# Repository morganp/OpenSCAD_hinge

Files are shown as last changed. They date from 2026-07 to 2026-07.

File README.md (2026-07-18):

# OpenSCAD_hinge

Parametric hinge library, plain OpenSCAD (no `BOSL2`, no third-party `include`s), for boxes,
lids, and wooden doors/cabinets. Loadable standalone in real OpenSCAD and by
[OpenSCAD-gui](../OpenSCAD-gui) (a custom JS OpenSCAD engine that resolves `include`/`use`
against its own drag-drop file provider and does not bundle BOSL2).

All modules live in `hinge_library.scad`. Each hinge type has a demo file under `examples/`
and a rendered preview under `renders/`.

## Usage

```openscad
include <hinge_library.scad>

knuckle_hinge(leaf_length=40, leaf_width=15, leaf_thickness=3, knuckle_od=6, knuckle_count=5);
```

Hinge axis convention: the barrel/knuckle axis runs along **Y** at x=0, z=knuckle radius, so
the closed hinge sits flat on the **Z=0** plane (printable as-is, barrel resting on the bed).
Leaf 1 occupies X<0, leaf 2 occupies X≥0, and the two leaves are separate solids with print
clearances, so each can be positioned/unioned directly onto its mating part. Units are mm.

---

## knuckle_hinge — print-in-place box lid hinge

Interleaved barrel knuckles across two leaves. By default the pin is integral to leaf 1 (its
knuckles are solid with the pin) and leaf 2's knuckles are bored with radial clearance, so the
part prints in place and articulates with no assembly. Set `integral_pin=false` for a
bored-both-sides hinge with an optional separately printed pin.

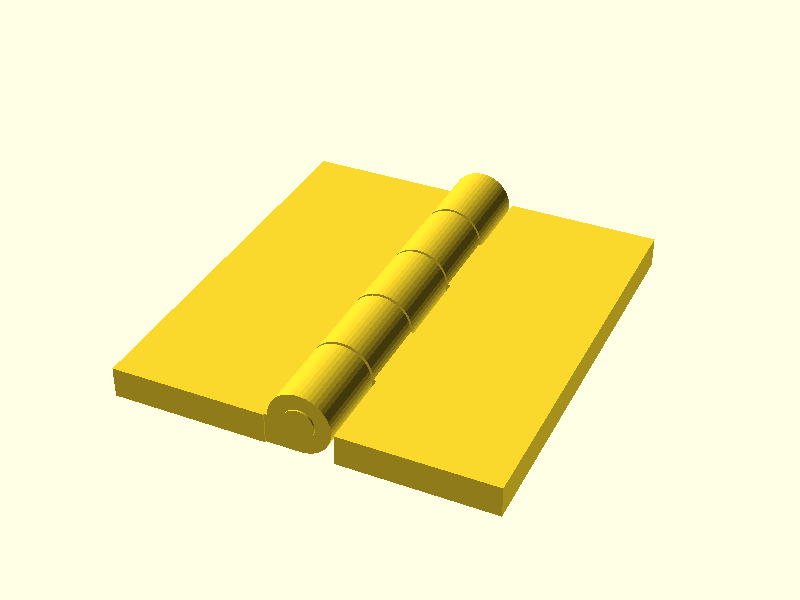
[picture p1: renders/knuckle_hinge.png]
knuckle_hinge render

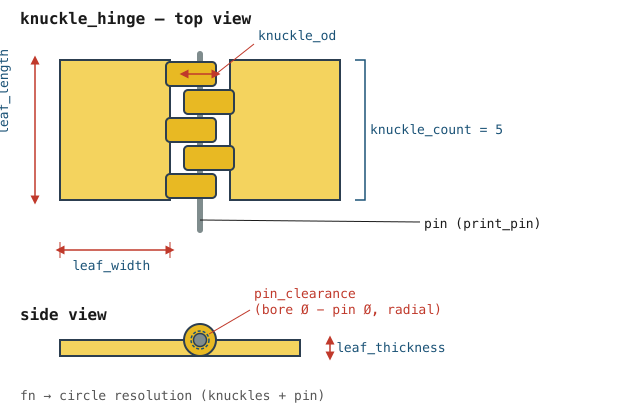
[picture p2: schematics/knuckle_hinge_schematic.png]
knuckle_hinge schematic


**[▶ Open in SCAD Studio](https://lizard-spock.co.uk/openscad-gui/?github=morganp/OpenSCAD_hinge/examples/knuckle_hinge_demo.scad)** — view this demo in the browser, no install.

| Parameter | Default | Meaning |
|---|---|---|
| `leaf_length` | 40 | Hinge length along the axis (Y) |
| `leaf_width` | 15 | Depth of each leaf plate (X), per leaf |
| `leaf_thickness` | 3 | Leaf plate thickness (Z) |
| `knuckle_od` | 6 | Knuckle/barrel outer diameter |
| `knuckle_count` | 5 | Number of knuckles across both leaves (odd = pin captive at both ends) |
| `pin_d` | 0 | Pin diameter; 0 = auto (`knuckle_od / 2`) |
| `pin_clearance` | 0.25 | Radial clearance between pin and knuckle bore |
| `knuckle_gap` | 0.3 | Axial clearance between adjacent knuckles, and leaf-to-barrel gap |
| `integral_pin` | true | Pin fused to leaf 1's knuckles (print-in-place, no assembly); `parts="both"` only, lone leaves are always bored |
| `print_pin` | false | With `integral_pin=false`: emit a loose pin beside the hinge |
| `cap_thickness` | 1.5 | `parts="caps"`: end cap flange thickness |
| `cap_plug_depth` | 0 | `parts="caps"`: cap stub depth into the bore; 0 = auto (half an end knuckle) |
| `parts` | "both" | `"both"` / `"leaf1"` / `"leaf2"` / `"pin"` / `"caps"`: emit one component only; a lone leaf is always bored for a loose pin, printed separately via `"pin"`, and `"caps"` emits a pair of gluable end caps that retain a cut-to-length metal rod pin |
| `fn` | 48 | `$fn`-style circle resolution for knuckles and pin |

---

## piano_hinge — continuous knuckle hinge, cut to any length

Same knuckle geometry as `knuckle_hinge`, but knuckle count is derived from `length` and a
target `knuckle_pitch`, for long lids needing even load distribution.

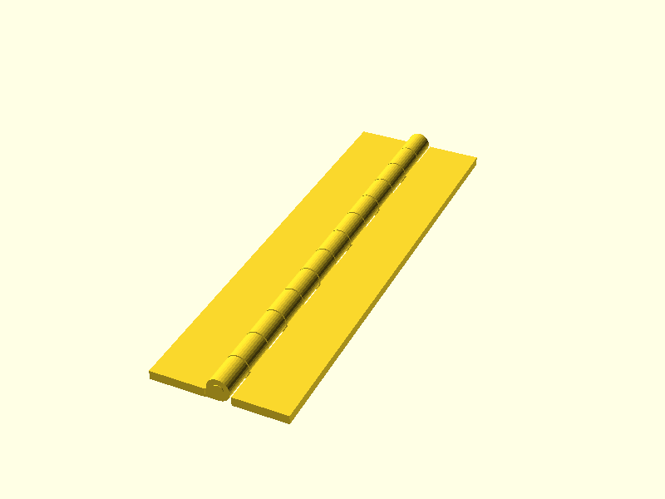
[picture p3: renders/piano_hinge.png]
piano_hinge render

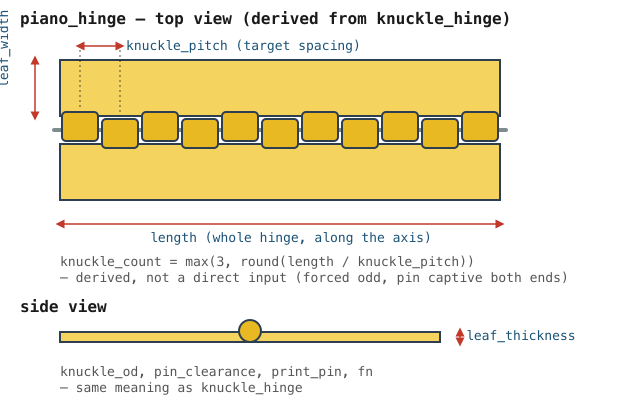
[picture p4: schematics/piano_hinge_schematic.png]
piano_hinge schematic


**[▶ Open in SCAD Studio](https://lizard-spock.co.uk/openscad-gui/?github=morganp/OpenSCAD_hinge/examples/piano_hinge_demo.scad)** — view this demo in the browser, no install.

| Parameter | Default | Meaning |
|---|---|---|
| `length` | 100 | Total hinge length along the axis |
| `leaf_width` | 12 | Depth of each leaf plate |
| `leaf_thickness` | 2 | Leaf plate thickness |
| `knuckle_od` | 5 | Knuckle outer diameter |
| `knuckle_pitch` | 8 | Target spacing between knuckle centers — knuckle count derived from `length / knuckle_pitch`, rounded up to odd, not set directly |
| `pin_d` | 0 | Pin diameter; 0 = auto |
| `pin_clearance` | 0.25 | Radial clearance between pin and bore |
| `knuckle_gap` | 0.3 | Axial knuckle clearance and leaf-to-barrel gap |
| `integral_pin` | true | Print-in-place pin fused to leaf 1; `parts="both"` only, lone leaves are always bored |
| `print_pin` | false | With `integral_pin=false`: emit a loose pin beside the hinge |
| `cap_thickness` | 1.5 | `parts="caps"`: end cap flange thickness |
| `cap_plug_depth` | 0 | `parts="caps"`: cap stub depth into the bore; 0 = auto (half an end knuckle) |
| `parts` | "both" | `"both"` / `"leaf1"` / `"leaf2"` / `"pin"` / `"caps"`: emit one component only; a lone leaf is always bored for a loose pin, printed separately via `"pin"`, and `"caps"` emits a pair of gluable end caps that retain a cut-to-length metal rod pin |
| `fn` | 32 | Circle resolution |

---

## living_hinge — flexible groove-cut strip hinge

Thin-wall, print-in-place fold hinge: parallel relief grooves alternate between the top and
bottom faces, each leaving a `web_thickness` web, so the strip flexes without a pin or
assembly.

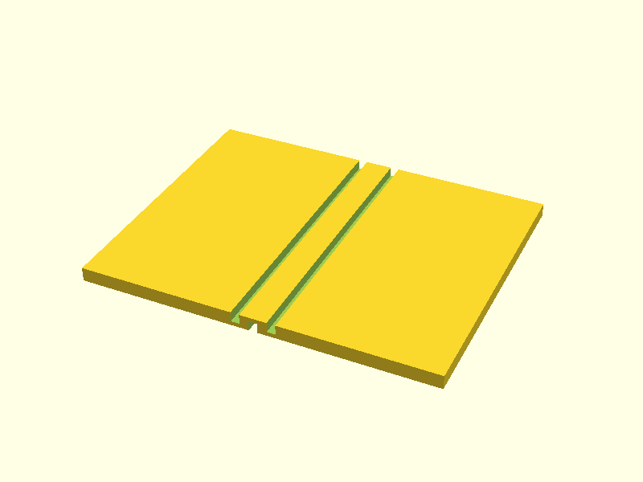
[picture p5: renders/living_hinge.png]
living_hinge render

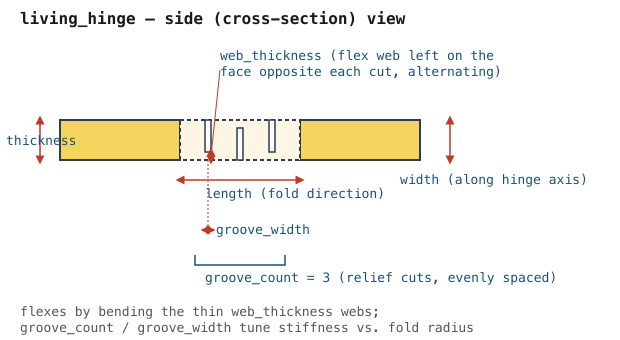
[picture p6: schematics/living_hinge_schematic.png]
living_hinge schematic


**[▶ Open in SCAD Studio](https://lizard-spock.co.uk/openscad-gui/?github=morganp/OpenSCAD_hinge/examples/living_hinge_demo.scad)** — view this demo in the browser, no install.

| Parameter | Default | Meaning |
|---|---|---|
| `width` | 40 | Extent along the hinge axis (Y) |
| `length` | 10 | Extent across the fold direction (X) |
| `thickness` | 2 | Parent wall thickness either side of the hinge |
| `web_thickness` | 0.6 | Thickness of the flexible web left after each groove cut |
| `groove_count` | 3 | Number of parallel relief grooves |
| `groove_width` | 1.2 | Width of each groove cut |

---

## door_butt_hinge — traditional mortise-plate hinge for wooden doors/cabinets

Hardware-pattern butt hinge: flat leaves, a knuckle barrel (built on `knuckle_hinge` with
`integral_pin=false`, both sides bored), a loose pin printed beside the hinge, and countersunk
screw holes down each leaf centerline. Model to spec for routing a mortise, or print directly
in a rigid filament.

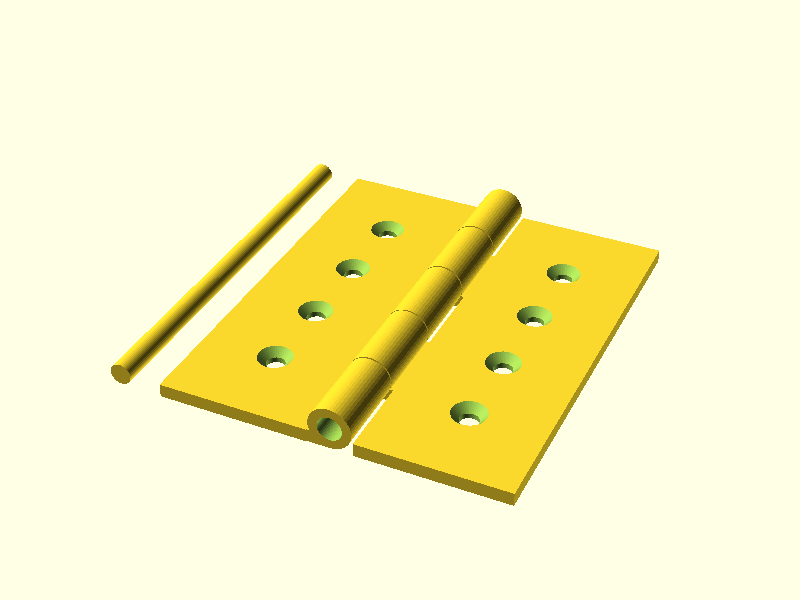
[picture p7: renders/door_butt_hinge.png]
door_butt_hinge render

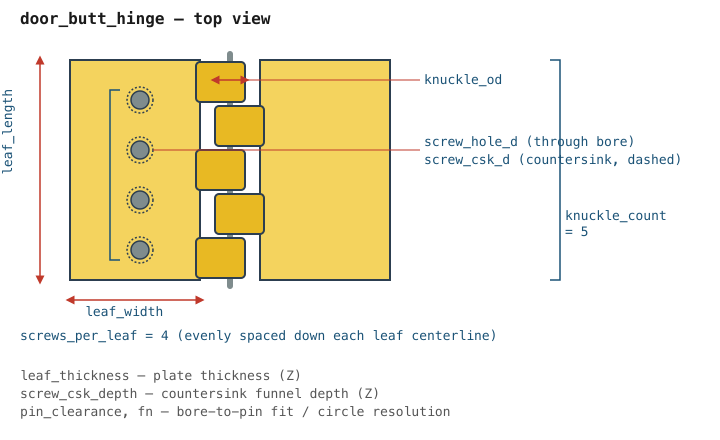
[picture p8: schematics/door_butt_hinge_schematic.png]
door_butt_hinge schematic


**[▶ Open in SCAD Studio](https://lizard-spock.co.uk/openscad-gui/?github=morganp/OpenSCAD_hinge/examples/door_butt_hinge_demo.scad)** — view this demo in the browser, no install.

| Parameter | Default | Meaning |
|---|---|---|
| `leaf_length` | 76 | Hinge length (e.g. 76mm ≈ a 3" hinge) |
| `leaf_width` | 28 | Depth of each leaf plate |
| `leaf_thickness` | 2.5 | Leaf plate thickness |
| `knuckle_od` | 8 | Knuckle outer diameter |
| `knuckle_count` | 5 | Number of knuckles |
| `screw_hole_d` | 3.5 | Screw through-hole diameter |
| `screw_csk_d` | 6.5 | Countersink diameter |
| `screw_csk_depth` | 1.5 | Countersink funnel depth |
| `screws_per_leaf` | 4 | Screw holes per leaf, evenly spaced down the centerline |
| `pin_d` | 0 | Pin diameter; 0 = auto |
| `pin_clearance` | 0.3 | Radial clearance between pin and bore |
| `knuckle_gap` | 0.3 | Axial knuckle clearance and leaf-to-barrel gap |
| `print_pin` | true | Emit the loose pin beside the hinge |
| `fn` | 48 | Circle resolution |

---

## snap_lid_hinge — pin-less friction/snap hinge for box lids

A thinned flex web flush with the top surface (so the lid folds up and over the top edge),
plus an over-center detent bump under the web, so a lid snaps open/closed without a pin or
any assembly step.

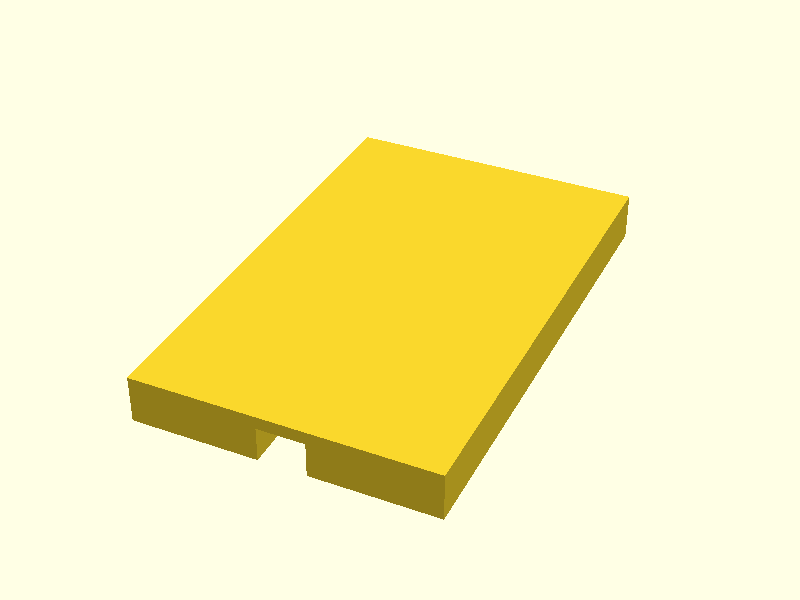
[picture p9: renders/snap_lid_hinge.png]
snap_lid_hinge render

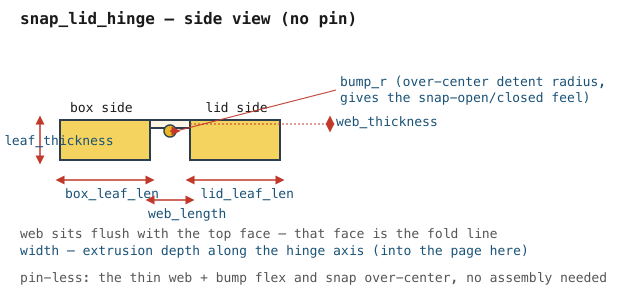
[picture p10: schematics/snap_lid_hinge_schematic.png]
snap_lid_hinge schematic


**[▶ Open in SCAD Studio](https://lizard-spock.co.uk/openscad-gui/?github=morganp/OpenSCAD_hinge/examples/snap_lid_hinge_demo.scad)** — view this demo in the browser, no install.

| Parameter | Default | Meaning |
|---|---|---|
| `width` | 30 | Extrusion depth along the hinge axis |
| `box_leaf_len` | 8 | Leaf length printed/glued into the box wall |
| `lid_leaf_len` | 8 | Leaf length printed/glued into the lid wall |
| `leaf_thickness` | 3 | Leaf thickness |
| `web_length` | 3 | Flex web length between the two leaves |
| `web_thickness` | 0.8 | Flex web thickness |
| `bump_r` | 0.6 | Over-center detent bump radius, gives the snap feel |

---

## removable_hinge — lift-off hinge, door removes without tools

Loose-joint hinge in two fully separable leaves, the pattern used for printer-enclosure and
cabinet doors that must come off without tools. Leaf 1 carries the lower barrel half with an
integral pin pointing up the axis; leaf 2 carries the upper barrel half with a blind bore open
at its lower end, so the door drops on and lifts straight off. Countersunk screw holes down
each leaf centerline.

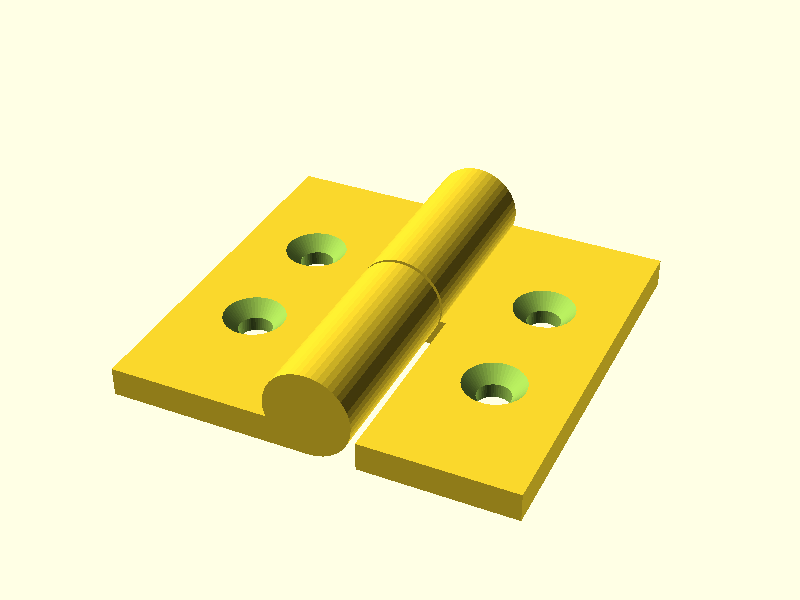
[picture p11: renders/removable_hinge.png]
removable_hinge render

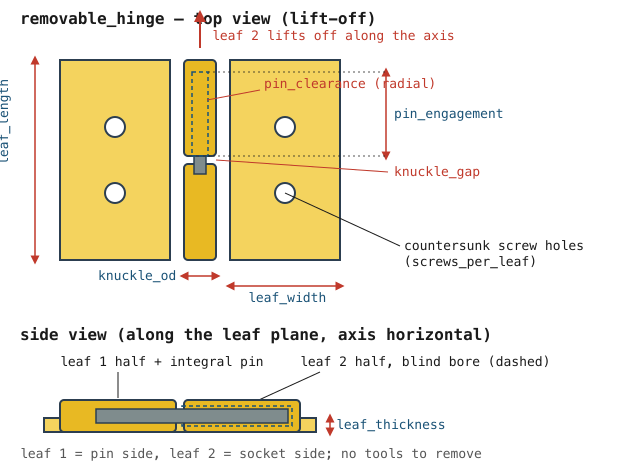
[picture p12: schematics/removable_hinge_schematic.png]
removable_hinge schematic


**[▶ Open in SCAD Studio](https://lizard-spock.co.uk/openscad-gui/?github=morganp/OpenSCAD_hinge/examples/removable_hinge_demo.scad)** — view this demo in the browser, no install.

| Parameter | Default | Meaning |
|---|---|---|
| `leaf_length` | 40 | Hinge length along the axis (Y); each leaf's barrel half takes ~half |
| `leaf_width` | 16 | Depth of each leaf plate |
| `leaf_thickness` | 3 | Leaf plate thickness |
| `knuckle_od` | 9 | Barrel outer diameter |
| `pin_d` | 0 | Pin diameter; 0 = auto (`knuckle_od / 2`) |
| `pin_clearance` | 0.3 | Radial clearance between pin and socket bore |
| `knuckle_gap` | 0.4 | Axial gap between the two barrel halves, and leaf-to-barrel gap |
| `pin_engagement` | 0 | Pin depth inside the socket; 0 = auto (blind bore, full depth) |
| `screw_hole_d` | 3.5 | Screw through-hole diameter |
| `screw_csk_d` | 6.5 | Countersink diameter |
| `screw_csk_depth` | 1.5 | Countersink funnel depth |
| `screws_per_leaf` | 2 | Screw holes per leaf |
| `fn` | 48 | Circle resolution |

---

## crate_hinge — rugged-box / sci-fi crate external lug hinge

External hinge in the rugged-box style: the barrel is raised above the mounting straps on
trapezoidal lug ribs, so the lid swings past 180° and the hardware reads as chunky external
detail. Leaf 1 owns the outer knuckles, leaf 2 the middle one(s); both sides are bored for a
loose pin (metal rod, screw, or the printed pin emitted beside the hinge). Cap-head
counterbored screw holes sit on the outer strip of each strap, clear of the lug ribs.

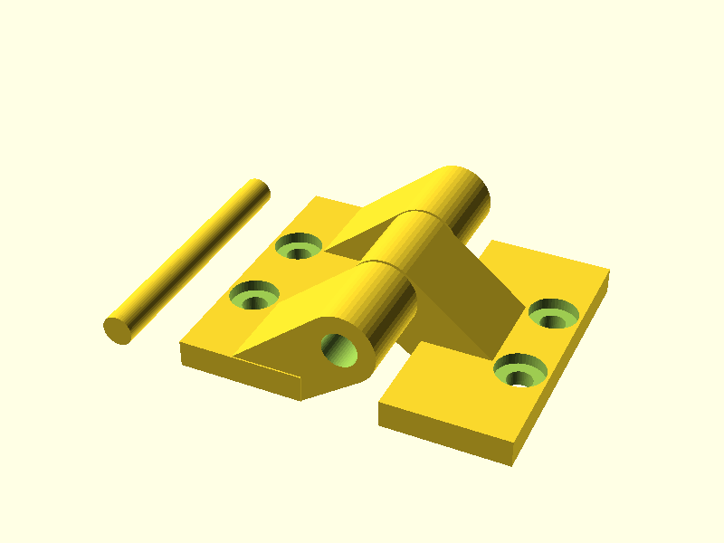
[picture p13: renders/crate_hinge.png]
crate_hinge render

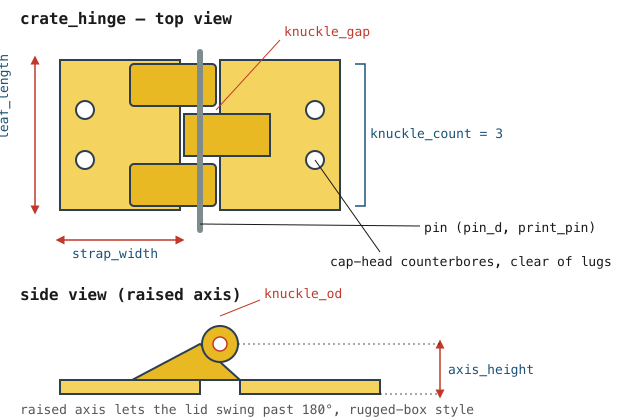
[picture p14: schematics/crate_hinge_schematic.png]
crate_hinge schematic


**[▶ Open in SCAD Studio](https://lizard-spock.co.uk/openscad-gui/?github=morganp/OpenSCAD_hinge/examples/crate_hinge_demo.scad)** — view this demo in the browser, no install.

| Parameter | Default | Meaning |
|---|---|---|
| `leaf_length` | 36 | Hinge length along the axis (Y) |
| `strap_width` | 16 | Mounting strap depth (X), per leaf |
| `strap_thickness` | 3.5 | Strap thickness |
| `knuckle_od` | 9 | Knuckle/lug barrel outer diameter |
| `knuckle_count` | 3 | Number of knuckles (odd = pin captive lugs at both ends on leaf 1) |
| `axis_height` | 0 | Hinge axis height above Z=0; 0 = auto (`knuckle_od`) |
| `pin_d` | 4 | Pin diameter, e.g. 4mm rod; 0 = auto (`knuckle_od / 2`) |
| `pin_clearance` | 0.25 | Radial clearance between pin and bore |
| `knuckle_gap` | 0.4 | Axial clearance between adjacent lugs |
| `screw_hole_d` | 3.2 | Screw through-hole diameter |
| `screw_cb_d` | 6.2 | Cap-head counterbore diameter |
| `screw_cb_depth` | 1.5 | Counterbore depth |
| `screws_per_leaf` | 2 | Screw holes per strap, on the outer strip; 0 = none (e.g. when fusing straps onto printed parts) |
| `print_pin` | true | `parts="both"` only: emit a loose printed pin beside the hinge |
| `cap_thickness` | 1.5 | `parts="caps"`: end cap flange thickness |
| `cap_plug_depth` | 0 | `parts="caps"`: cap stub depth into the bore; 0 = auto (half an end knuckle) |
| `parts` | "both" | `"both"` / `"leaf1"` / `"leaf2"` / `"pin"` / `"caps"`: emit one component only; a lone leaf is always bored for a loose pin, printed separately via `"pin"`, and `"caps"` emits a pair of gluable end caps that retain a cut-to-length metal rod pin |
| `fn` | 48 | Circle resolution |

---

## flush_knuckle_hinge — full-thickness leaf knuckle hinge

Like `knuckle_hinge`, but each leaf plate is as thick as the knuckle barrel and runs right up
to the hinge axis. A cylindrical scallop is cut along each leaf's inner edge between its own
knuckles, so the opposing leaf's knuckles nest into the plate with close radial tolerance.
There is no thin plate-to-barrel neck (stronger than `knuckle_hinge`), the barrel sits flush
inside the leaf edges, and the scallop radius is exactly what the geometry needs for a full
0–180° swing: the hinge closes flat and folds flat.

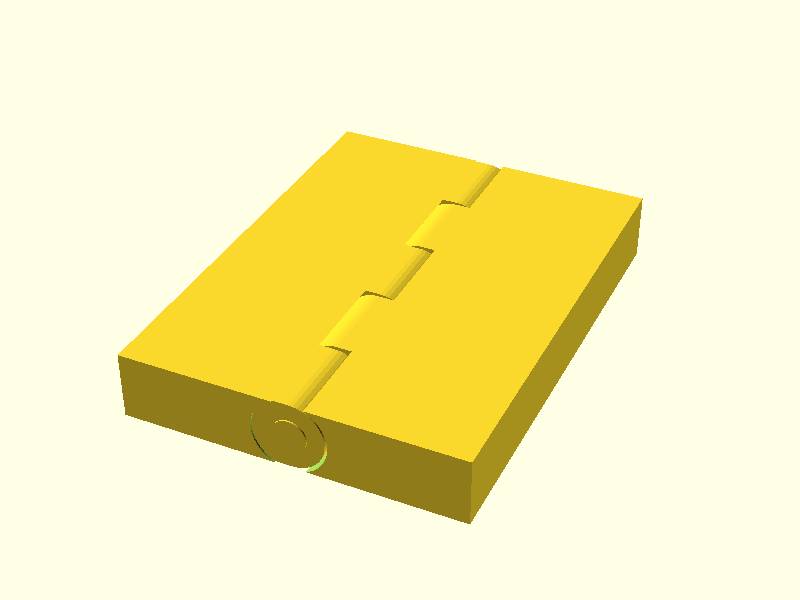
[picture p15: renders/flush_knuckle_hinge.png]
flush_knuckle_hinge render

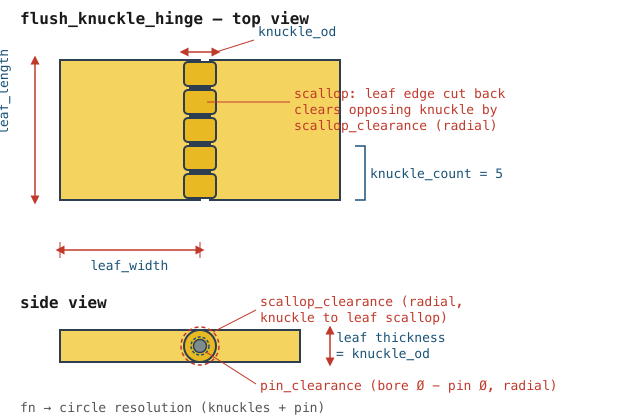
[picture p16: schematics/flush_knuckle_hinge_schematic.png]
flush_knuckle_hinge schematic


**[▶ Open in SCAD Studio](https://lizard-spock.co.uk/openscad-gui/?github=morganp/OpenSCAD_hinge/examples/flush_knuckle_hinge_demo.scad)** — view this demo in the browser, no install.

A micro variant (`examples/flush_knuckle_hinge_micro_demo.scad`, render
`renders/flush_knuckle_hinge_micro.png`) shows the same hinge at 2mm knuckle/leaf thickness
with a 0.8mm pin and tightened clearances.
**[▶ Open micro variant in SCAD Studio](https://lizard-spock.co.uk/openscad-gui/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)**

Print notes (0.4mm nozzle, 0.16mm layers, 3 walls, 3% infill reference profile):

- Wall width is not the limit: a 0.4mm nozzle with variable line width (Arachne) prints
  lines down to ~0.24mm, so the micro variant's 0.45mm bore wall and 0.8mm pin are printable.
- Clearance vs layer height is the limit: `pin_clearance=0.15` is below one 0.16mm layer, so
  the vertical gap around the pin rounds to a single layer and may fuse. If the pin seizes,
  bump `pin_clearance` to 0.2 and `scallop_clearance` to 0.25.
- Infill barely matters: hinge loads run through knuckles and pin, which are
  perimeter-dominated; 3 walls carry it.
- First-layer squish narrows the scallop gap at bed level — if leaves fuse along the bottom
  of the seam, raise `scallop_clearance` or reduce first-layer flow.
- If the printed hinge binds before 90° (test-print confirmed at this scale), the bottom
  edge of each knuckle is dragging on the opposing leaf's seam lip. Set `back_relief`
  (micro demo uses 0.35 deep, auto width) to cut a narrow notch into each leaf's lip beside
  every opposing-knuckle segment — each leaf's own material only, alternating sides section
  by section, spanning the knuckle's full overlap over the lip with `scallop_clearance`
  margin at both walls (printed knuckles run wider than nominal); the swing then clears
  through the full range and the knuckles keep their full height.

| Parameter | Default | Meaning |
|---|---|---|
| `leaf_length` | 40 | Hinge length along the axis (Y) |
| `leaf_width` | 15 | Depth of each leaf plate (X), axis to outer edge |
| `knuckle_od` | 6 | Knuckle/barrel outer diameter, also the leaf plate thickness |
| `knuckle_count` | 5 | Number of knuckles across both leaves (odd = pin captive at both ends) |
| `pin_d` | 0 | Pin diameter; 0 = auto (`knuckle_od / 2`) |
| `pin_clearance` | 0.25 | Radial clearance between pin and knuckle bore |
| `knuckle_gap` | 0.3 | Axial clearance between adjacent knuckles |
| `scallop_clearance` | 0.3 | Radial clearance between a knuckle and the opposing leaf's scallop |
| `back_relief` | 0 | Depth of a narrow notch cut into each leaf's scallop lip beside every opposing-knuckle segment, where that knuckle's bottom edge lands; cut into the leaf's own material only, frees the swing when the print binds |
| `back_relief_width` | 0 | Width of each notch; 0 = auto, spans the knuckle's full overlap over the lip plus `scallop_clearance` margin at both walls (printed knuckles run wider than nominal) |
| `integral_pin` | true | Pin fused to leaf 1's knuckles (print-in-place, no assembly); `parts="both"` only, lone leaves are always bored |
| `print_pin` | false | With `integral_pin=false`: emit a loose pin beside the hinge |
| `cap_thickness` | 1.5 | `parts="caps"`: end cap flange thickness |
| `cap_plug_depth` | 0 | `parts="caps"`: cap stub depth into the bore; 0 = auto (half an end knuckle) |
| `parts` | "both" | `"both"` / `"leaf1"` / `"leaf2"` / `"pin"` / `"caps"`: emit one component only; a lone leaf is always bored for a loose pin, printed separately via `"pin"`, and `"caps"` emits a pair of gluable end caps that retain a cut-to-length metal rod pin |
| `fn` | 48 | `$fn`-style circle resolution for knuckles, scallop, and pin |

---

## Regenerating previews

```sh
openscad -o renders/<name>.png --imgsize=800,600 --autocenter --viewall examples/<name>_demo.scad
```

Schematics are hand-authored SVGs in `schematics/`, rasterized with `rsvg-convert -o out.png in.svg`.

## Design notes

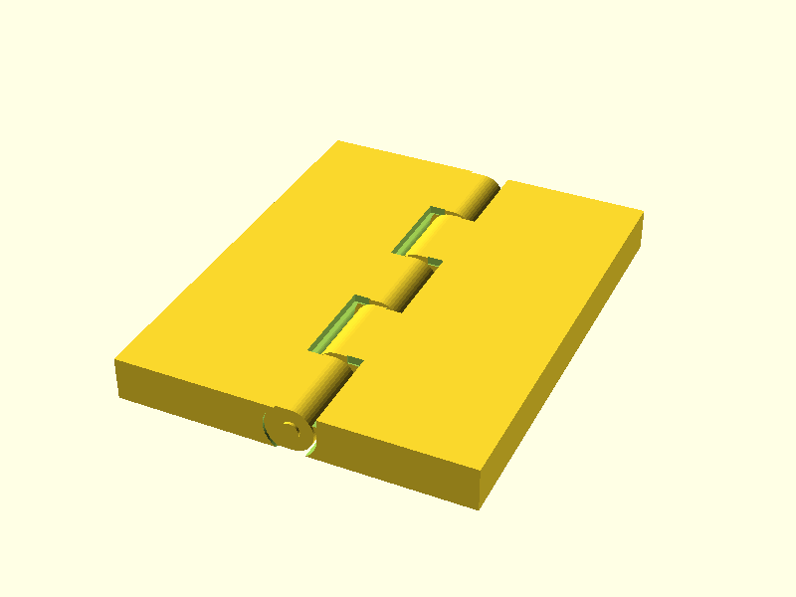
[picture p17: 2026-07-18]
renders/flush_knuckle_hinge_micro.png

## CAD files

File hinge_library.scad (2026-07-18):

// hinge_library.scad
// Parametric hinge library, plain OpenSCAD, no external includes.
// Loadable standalone in OpenSCAD and by OpenSCAD-gui (../OpenSCAD-gui).
//
// Hinge axis convention: barrel/knuckle axis runs along Y at x=0, z=knuckle
// radius, so the whole hinge sits flat on the Z=0 plane (printable as-is).
// Leaf 1 occupies X<0, leaf 2 occupies X>=0; each leaf is a separate solid
// so it can be positioned/unioned onto its own mating part, and the barrel
// clearances leave the joint free to rotate.

// ---------------------------------------------------------------------------
// Shared: gluable pin end cap. Disc flange sized to the knuckle face plus a
// pin-diameter stub that glues into the end knuckle bore, capping and
// retaining a cut-to-length metal rod (or printed) pin. The pinned hinge
// modules emit a pair of these via parts="caps"; they print flange-down.
// ---------------------------------------------------------------------------
module hinge_pin_cap(knuckle_od, pin_d, cap_thickness, plug_depth, fn) {
    cylinder(h=cap_thickness, d=knuckle_od, $fn=fn);
    translate([0, 0, cap_thickness])
        cylinder(h=plug_depth, d=pin_d, $fn=fn);
}

// ---------------------------------------------------------------------------
// 1. knuckle_hinge, print-in-place barrel hinge for box lids.
//    Interleaved knuckles on two leaves. By default the pin is integral to
//    leaf 1 (its knuckles are solid with the pin) and leaf 2's knuckles are
//    bored with radial clearance, so the printed part articulates with no
//    assembly. Set integral_pin=false for a bored-both-sides hinge with an
//    optional separately printed pin (print_pin=true).
// ---------------------------------------------------------------------------
module knuckle_hinge(
    leaf_length    = 40,   // length along Y (hinge axis)
    leaf_width     = 15,   // depth along X, per leaf, excluding barrel
    leaf_thickness = 3,
    knuckle_od     = 6,
    knuckle_count  = 5,    // total knuckles across both leaves (odd = pin captive at both ends)
    pin_d          = 0,    // pin diameter; 0 = auto (knuckle_od / 2)
    pin_clearance  = 0.25, // radial clearance between pin and knuckle bore
    knuckle_gap    = 0.3,  // axial clearance between adjacent knuckles, and leaf-to-barrel gap
    integral_pin   = true, // pin fused to leaf 1's knuckles (print-in-place, parts="both" only)
    print_pin      = false,// integral_pin=false only: emit loose pin beside the hinge
    cap_thickness  = 1.5,  // parts="caps": end cap flange thickness
    cap_plug_depth = 0,    // parts="caps": stub depth into the bore; 0 = auto (half an end knuckle)
    parts          = "both", // "both" | "leaf1" | "leaf2" | "pin" | "caps": emit one component
                             // only, so a caller can fuse each leaf onto a different part (lid vs
                             // box) and print the loose pin, or a pair of gluable pin end caps
                             // (for metal rod pins), as its own piece
    fn             = 48
) {
    knuckle_r = knuckle_od / 2;
    axis_z    = knuckle_r;               // barrel rests on the Z=0 plane
    seg       = leaf_length / knuckle_count;
    pin_r     = (pin_d > 0 ? pin_d : knuckle_od / 2) / 2;
    bore_r    = pin_r + pin_clearance;
    edge      = knuckle_r + knuckle_gap; // leaf plate inner edge, clears the barrel

    module barrel_seg(i) {
        translate([0, -leaf_length/2 + i*seg + knuckle_gap/2, axis_z])
            rotate([-90, 0, 0])
                cylinder(h=seg - knuckle_gap, r=knuckle_r, $fn=fn);
    }

    // bridges the plate-to-barrel gap, only across this leaf's own knuckles
    module neck(sign, i) {
        translate([sign > 0 ? 0 : -(edge + 0.5),
                   -leaf_length/2 + i*seg + knuckle_gap/2, 0])
            cube([edge + 0.5, seg - knuckle_gap, leaf_thickness]);
    }

    module plate(sign) {
        translate([sign > 0 ? edge : -(edge + leaf_width), -leaf_length/2, 0])
            cube([leaf_width, leaf_length, leaf_thickness]);
    }

    // sign=-1 owns even-index knuckles (both ends when count is odd)
    module leaf(sign) {
        plate(sign);
        for (i = [0:knuckle_count-1])
            if ((i % 2 == 0) == (sign < 0)) {
                barrel_seg(i);
                neck(sign, i);
            }
    }

    module bore() {
        translate([0, -leaf_length/2 - 1, axis_z])
            rotate([-90, 0, 0])
                cylinder(h=leaf_length + 2, r=bore_r, $fn=fn);
    }

    // leaf 1 (X<0); a lone leaf is always bored, an integral pin can only
    // articulate when both leaves print in place around it
    if (parts == "both" && integral_pin) {
        leaf(-1);
        translate([0, -leaf_length/2, axis_z])
            rotate([-90, 0, 0])
                cylinder(h=leaf_length, r=pin_r, $fn=fn);
    } else if (parts == "both" || parts == "leaf1") {
        difference() { leaf(-1); bore(); }
    }

    // leaf 2 (X>=0), always bored
    if (parts == "both" || parts == "leaf2")
        difference() { leaf(1); bore(); }

    // loose pin: its own print (parts="pin", on the bed at the origin) or
    // emitted beside a bored-both-sides pair
    if (parts == "pin")
        translate([0, 0, pin_r])
            rotate([-90, 0, 0])
                cylinder(h=leaf_length - knuckle_gap, r=pin_r, center=true, $fn=fn);
    else if (parts == "both" && !integral_pin && print_pin)
        translate([-(edge + leaf_width + knuckle_od), 0, pin_r])
            rotate([-90, 0, 0])
                cylinder(h=leaf_length - knuckle_gap, r=pin_r, center=true, $fn=fn);

    // pair of gluable end caps for a rod pin, flange-down on the bed
    if (parts == "caps")
        for (s = [-1, 1])
            translate([s * knuckle_od, 0, 0])
                hinge_pin_cap(knuckle_od, pin_r * 2, cap_thickness,
                              cap_plug_depth > 0 ? cap_plug_depth : seg / 2, fn);
}

// ---------------------------------------------------------------------------
// 2. piano_hinge, continuous knuckle hinge, cut to any length.
//    Same geometry as knuckle_hinge but knuckle_count is derived from length
//    and a fixed pitch, for long lids that need even load distribution.
// ---------------------------------------------------------------------------
module piano_hinge(
    length         = 100,
    leaf_width     = 12,
    leaf_thickness = 2,
    knuckle_od     = 5,
    knuckle_pitch  = 8,   // approx spacing between knuckle centers
    pin_d          = 0,
    pin_clearance  = 0.25,
    knuckle_gap    = 0.3,
    integral_pin   = true,
    print_pin      = false,
    cap_thickness  = 1.5,
    cap_plug_depth = 0,
    parts          = "both",
    fn             = 32
) {
    // force an odd count so the pin is captive at both ends
    raw = max(3, round(length / knuckle_pitch));
    n   = raw % 2 == 0 ? raw + 1 : raw;
    knuckle_hinge(
        leaf_length    = length,
        leaf_width     = leaf_width,
        leaf_thickness = leaf_thickness,
        knuckle_od     = knuckle_od,
        knuckle_count  = n,
        pin_d          = pin_d,
        pin_clearance  = pin_clearance,
        knuckle_gap    = knuckle_gap,
        integral_pin   = integral_pin,
        print_pin      = print_pin,
        cap_thickness  = cap_thickness,
        cap_plug_depth = cap_plug_depth,
        parts          = parts,
        fn             = fn
    );
}

// ---------------------------------------------------------------------------
// 3. living_hinge, flexible groove-cut strip hinge for thin-wall,
//    print-in-place lids. Relief grooves alternate top/bottom faces, each
//    leaving a web of web_thickness, so the strip flexes without tearing.
// ---------------------------------------------------------------------------
module living_hinge(
    width         = 40,  // along Y
    length        = 10,  // fold direction, along X
    thickness     = 2,   // parent wall thickness either side of the hinge
    web_thickness = 0.6, // flexible web left behind each groove cut
    groove_count  = 3,   // number of parallel relief grooves
    groove_width  = 1.2
) {
    cut_h   = thickness - web_thickness + 0.05; // overcut past the face
    spacing = length / (groove_count + 1);
    difference() {
        cube([length, width, thickness], center=true);
        for (i = [1:groove_count]) {
            x    = -length/2 + i*spacing;
            side = (i % 2 == 1) ? 1 : -1; // alternate: cut from top, then bottom
            translate([x, 0, side * (thickness/2 + 0.05 - cut_h/2)])
                cube([groove_width, width + 1, cut_h], center=true);
        }
    }
}
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

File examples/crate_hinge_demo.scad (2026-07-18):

// @github: morganp/OpenSCAD_hinge
include <../hinge_library.scad>

crate_hinge(
    leaf_length     = 36,
    strap_width     = 16,
    strap_thickness = 3.5,
    knuckle_od      = 9,
    knuckle_count   = 3,
    pin_d           = 4,    // sized for a 4mm metal rod; 0 = auto (knuckle_od / 2)
    pin_clearance   = 0.25,
    knuckle_gap     = 0.4,
    screws_per_leaf = 2,
    print_pin       = true
);

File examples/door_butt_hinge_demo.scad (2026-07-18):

// @github: morganp/OpenSCAD_hinge
include <../hinge_library.scad>

door_butt_hinge(
    leaf_length    = 76,
    leaf_width     = 28,
    leaf_thickness = 2.5,
    knuckle_od     = 8,
    knuckle_count  = 5,
    pin_d          = 0,    // 0 = auto (knuckle_od / 2 = 4mm); set explicitly to suit a metal rod pin
    screw_hole_d   = 3.5,
    screw_csk_d    = 6.5,
    screws_per_leaf= 4
);

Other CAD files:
examples/flush_knuckle_hinge_demo.scad
examples/flush_knuckle_hinge_micro_demo.scad
examples/knuckle_hinge_demo.scad
examples/living_hinge_demo.scad
examples/piano_hinge_demo.scad
examples/removable_hinge_demo.scad
examples/snap_lid_hinge_demo.scad

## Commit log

2026-07-07 Add parametric hinge library: 5 hinge types, docs, renders
    Vanilla OpenSCAD (no BOSL2) so it loads standalone in OpenSCAD-gui.
    knuckle_hinge, piano_hinge, living_hinge, door_butt_hinge, snap_lid_hinge,
    each with a demo file, rendered PNG, and an annotated parameter schematic.
    [door_butt_hinge_demo.scad, hinge_library.scad, knuckle_hinge_demo.scad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]
2026-07-07 Redesign all hinge geometry so joints actually articulate
    Previous geometry was non-functional: knuckles were vertical pillars
    fused across both leaves, the pin floated beside the hinge, living
    hinge grooves cut clean through the web, and the snap hinge detent
    bump ran along the wrong axis.
    - knuckle_hinge: barrels along Y at z=knuckle radius (prints flat on
    bed), leaf 1 owns even knuckles with integral pin, leaf 2 bored with
    clearance; leaves are separate free solids. New pin_d, knuckle_gap,
    integral_pin params; include_leaves removed.
    - piano_hinge: derives odd knuckle count so pin is captive both ends.
    - door_butt_hinge: built as difference over knuckle core with loose
    pin; count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
    [hinge_library.scad, knuckle_hinge_demo.scad, piano_hinge_demo.scad]
2026-07-07 README: add Open in SCAD Studio deep links to all five hinge demos
2026-07-07 Tag every demo with // @github: morganp/OpenSCAD_hinge
    SCAD Studio scans this comment above an include to auto-fetch the
    library repo, so demo files opened individually (or code copied out of
    the editor) resolve hinge_library.scad without a full-repo deep link.
    Real OpenSCAD treats it as a plain comment; all five demos still
    compile clean in both engines.
    [door_butt_hinge_demo.scad, knuckle_hinge_demo.scad, living_hinge_demo.scad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]
2026-07-08 Add removable (lift-off) and crate (rugged-box) hinge types
    removable_hinge: two separable leaves, integral pin on leaf 1, blind
    socket bore on leaf 2, so a door drops on and lifts off without tools.
    crate_hinge: external lug hinge with the barrel raised on trapezoidal
    ribs above the mounting straps, rugged-box style, loose pin through
    three interleaved knuckles.
    Each with demo, render, schematic, and README/CLAUDE.md docs.
    [crate_hinge_demo.scad, hinge_library.scad, removable_hinge_demo.scad]
2026-07-08 CLAUDE.md: document full new-hinge checklist
    Workflow previously listed only module + demo + render + table row.
    Spell out the schematic SVG/PNG step, the README section template,
    and the SCAD Studio deep-link URL pattern so future additions stay
    consistent without inferring from existing sections.
2026-07-09 Fix schematic geometry to match module code
    Six of the seven schematics drew geometry that contradicted the
    library modules; only crate_hinge was correct.
    - knuckle, piano, door_butt top views: knuckles were end-on circles;
    now alternating rect segments along the axis, pin underneath
    - piano: leaves re-laid out along the axis, pitch between seg centers
    - removable side view: show the two barrel halves offset along the
    axis with the integral pin entering the dashed blind bore
    - knuckle side view: bore/pin detail and pin_clearance moved here,
    where the bore is actually visible
    - snap_lid: web flush with the top face, detent bump underneath
    - living: single alternating top/bottom cuts, w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
2026-07-09 Add parts param to knuckle/piano/crate hinges for per-part leaf fusing
    parts="both"|"leaf1"|"leaf2" emits a single leaf so a caller (e.g.
    OpenSCAD_case's hinged_box) can fuse each leaf onto a different printed
    part and join them with the pin at assembly. Also guard crate_hinge
    screw holes for screws_per_leaf=0, for fused straps that need no screws.
    [hinge_library.scad]
2026-07-11 Add flush_knuckle_hinge, full-thickness leaf knuckle hinge
    Leaf plate is as thick as the knuckle barrel and runs to the axis
    plane; a cylindrical scallop (knuckle_r + scallop_clearance) cut
    along each leaf's inner edge lets the opposing knuckles nest into
    the plate at close radial tolerance. The scallop radius is exactly
    what the geometry needs for a 0-180 degree swing: points inside it
    stay in the relief void, points outside arc over the other leaf's
    top face, so the hinge closes flat and folds flat. No thin
    plate-to-barrel neck, so stronger than knuckle_hinge.
    Full checklist: module, demo, render, schematic SVG/PNG, CLAUDE.md
    table row, README section. Demo and all parts/integral_pin vari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
    [flush_knuckle_hinge_demo.scad, hinge_library.scad]
2026-07-11 Show parts param in flush_knuckle_hinge demo
    [flush_knuckle_hinge_demo.scad]
2026-07-11 Add micro flush_knuckle_hinge example, 2mm knuckle, 0.8mm pin
    Tightened clearances (pin 0.15, scallop 0.2, axial 0.25) for the
    small scale; bore wall is 0.45mm so the demo notes a fine-nozzle
    print. Exports manifold STL.
    [flush_knuckle_hinge_micro_demo.scad]
2026-07-11 README: print notes for flush_knuckle_hinge micro variant
    0.4mm nozzle with Arachne prints ~0.24mm lines, so the 0.45mm bore
    wall and 0.8mm pin are printable; the real print-in-place limit is
    clearance vs layer height (0.15mm pin clearance rounds to a single
    0.16mm layer and may fuse). Document tuning fallbacks and why 3%
    infill is fine for hinges.
2026-07-18 feat: add back_relief and rod-pin end caps
    - flush_knuckle_hinge: back_relief trims a flat off the top face of
    each knuckle where it protrudes into the opposing scallop; the CAD
    swing was already clear but the printed micro hinge bound before
    90 degrees (test print), so relieve the contact zone
    - knuckle/piano/crate/flush: parts="caps" emits a pair of gluable end
    plugs (knuckle_od flange + pin_d stub) that retain a cut-to-length
    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
    [crate_hinge_demo.scad, door_butt_hinge_demo.scad, flush_knuckle_hinge_demo.scad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]
2026-07-18 fix: back_relief cuts each leaf's own side of the hinge line
    Test print showed the bind is the opposing knuckles dragging over the
    scallop's top lip, not the knuckle tops themselves: trim the lip and
    the inner knuckle half on each leaf's own side instead of the
    protruding half. Micro demo settles on back_relief 0.35 (0.45 left
    tangent-thin bore walls).
    [flush_knuckle_hinge_micro_demo.scad, hinge_library.scad]
2026-07-18 feat: narrow back_relief to a band via back_relief_width
    Test print at 90 degrees showed only a ~0.1mm strip at the seam
    binds; the rest of the knuckle regains full height. Width 0 = auto
    (knuckle_od / 20).
    [flush_knuckle_hinge_micro_demo.scad, hinge_library.scad]
2026-07-18 fix: start back_relief notch at the seam lip, not the pin line
    Test print showed the bind is the opposing knuckles' bottom edge
    landing just outside the scallop lip; each leaf's notch now runs
    outward from sqrt(scallop_r^2 - knuckle_r^2), offset to its own side.
    Notch no longer nears the pin bore, so the depth breakout limit is
    gone.
    [flush_knuckle_hinge_micro_demo.scad, hinge_library.scad]
2026-07-18 feat: cut back_relief notches on both sides of every leaf
    Each knuckle section now gets the seam-lip notch on both flanks, not
    just the leaf's own side; micro demo widens the notch to 0.2.
    [flush_knuckle_hinge_micro_demo.scad, hinge_library.scad]
2026-07-18 fix: back_relief notches cut per segment into own lip, full knuckle width
    Two test-print corrections: notch only the leaf's own scallop lip
    beside each opposing-knuckle segment (previous cut chewed the opposing
    knuckle flanks), and auto width now spans the knuckle's full overlap
    over the lip (knuckle_r - lip edge) instead of knuckle_od/20, which
    left the outer part of the drag zone unrelieved.
    [flush_knuckle_hinge_micro_demo.scad, hinge_library.scad]
2026-07-18 fix: widen back_relief notch by scallop_clearance at both walls
    Printed knuckles bulge past nominal knuckle_r and the lip crest
    bulges inward, so the edge-to-edge notch still left drag strips at
    both walls (test print). Auto notch now runs from lip_edge -
    scallop_clearance out to knuckle_r + scallop_clearance.
    [hinge_library.scad]
2026-07-18 fix: extend back_relief notch past knuckle ends along the axis
    Printed knuckles also run longer than nominal; the bare knuckle_gap/2
    overhang left end walls the knuckle ends dragged on (seen in preview
    and print). Notch now runs scallop_clearance past each segment end.
    [hinge_library.scad]
